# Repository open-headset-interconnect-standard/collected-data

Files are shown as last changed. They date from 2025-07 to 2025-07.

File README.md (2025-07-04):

# collected-data
Measurement data that has been collected first-hand, that would benefit the community.

That is to say: don't post information you got from somewhere else here.

## What to include
To create a pull-request into this repo (read: to publish data here):

* Create your own directory for the data, unless you are contributing to an existing collection of measurements.
* Create a `README.md` in that directory that explains what the data is and why it's useful to the community (if not obvious).
* Include the measurement meathodology:
  * What measurement equipment was used?  Make and model, where appropriate.  Was is calibrated?
  * Configuration of measurement equipment, device under test, and anything else relevant.  What was connected to what?
  * Any other relevant information that would help a reader understand just what they're looking at.
* Include the data in both raw format, and analyzed format, where appropriate.  For example:
  * Include an image that shows the conclusion quickly: "The SWR at 145MHz is 1.2:1"
  * Include the .s2p file that was used to generate that conclusion, so that others can analyze the data differently: "Sure, but it's entirely reactive. The X=0 point is at 162MHz."  Or whatever.

@SmittyHalibut 2025-07-02

# Data!

[Audio Isolation Transformer measurements](Audio%20Transformers/)

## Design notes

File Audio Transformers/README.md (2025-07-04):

# 1. Audio Transformer measurements

- [1. Audio Transformer measurements](#1-audio-transformer-measurements)
    - [1.1. Measurement setup](#11-measurement-setup)
- [2. Measurement Results](#2-measurement-results)
    - [2.1. Through Calibration](#21-through-calibration)
    - [2.2. Bourns SM-LP-5001](#22-bourns-sm-lp-5001)
    - [2.3. PXSW PX-MB-CPC E-9818](#23-pxsw-px-mb-cpc-e-9818)
    - [2.4. ED8 Permalloy](#24-ed8-permalloy)
    - [2.5. EI-14 eBay](#25-ei-14-ebay)
    - [2.6. EI-14 TL016 "Mouser" (Xicon?)](#26-ei-14-tl016-mouser-xicon)
- [3. All transformers, compared by voltage](#3-all-transformers-compared-by-voltage)
    - [3.1. 100mV](#31-100mv)
    - [3.2. 3V](#32-3v)
- [4. Test Board Details](#4-test-board-details)

I got reports that audio frequency response was ... pretty terrible ... on a product I made.  So I wanted to measure the actual frequency response of several 1:1 audio transformers to see if there were better options.

I made a [circuit board](#3-test-board-details) that would take several common transformer footprints and present their inputs and outputs with BNC sockets (for easy connection to my test gear), bought several transformers, wired it all up, and got to measuring!

In the immortal words of Mark Watney:
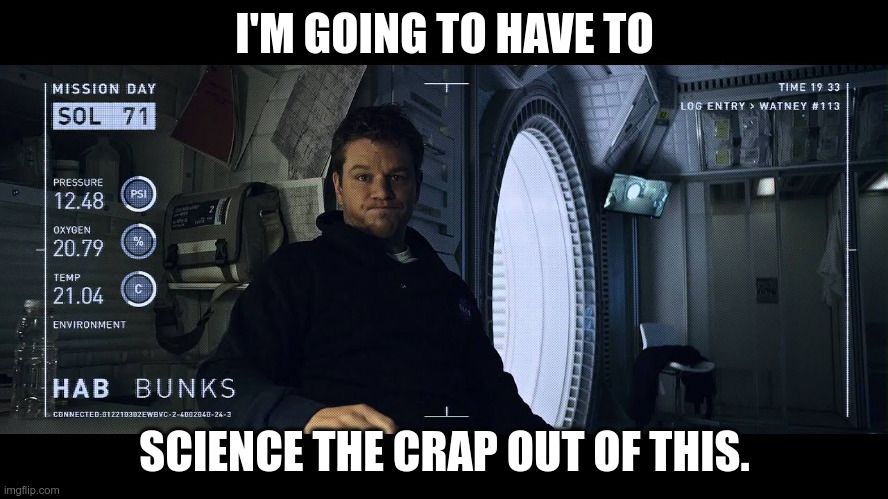
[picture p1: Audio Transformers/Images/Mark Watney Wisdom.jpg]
I'm going to have to Science the CRAP out of this.


> @SmittyHalibut 2025-07-02

## 1.1. Measurement setup

I designed a [test board](#3-test-board-details) and soldered several different audio transformers to each one.  The board has BNC sockets for easy connection to my other gear.

I used an [Analog Discovery 2](https://digilent.com/shop/analog-discovery-2-100ms-s-usb-oscilloscope-logic-analyzer-and-variable-power-supply/) to take all measurements.  It had a [BNC Adapter](https://digilent.com/shop/bnc-adapter-for-analog-discovery/) attached.  The signal generator was set to 50&Omega;, and the scope was set to DC coupled.

I used [Waveforms](https://digilent.com/shop/out-of-the-box-solutions/) to perform the measurements.  The Workspace configuration file is [included here](./Data/Audio%20Network%20Analyzer.dwf3work).

In short, it uses the Network tool to measure Amplitude, Phase, THD and THD+N.  A script automates taking the same measurements at several signal voltage levels ranging from 100mV to 5V.  The load on the secondary side of the transformers in a 1k&Omega; resistor, so you can calculate the power being transferred.

The cables were 1m long RG316 with BNC males on either end, purchased from [Packtenna](https://www.packtenna.com/store/p14/3%27_RG-316_Coax_with_2_Right_Angle_BNC_connectors.html#/).  Wavegen1 and Scope2 were connected together with a BNC T (remember those? THIS IS WHY WE HOARD) to the Primary of the transformer.  Scope1 was connected to the Secondary of the transformer.

The test boards (below) allow you to put a component in series and parallel with each input and output.  For these measurements, I used a 0&Omega; jumper in series, and a 1k&Omega; resistor in parallel with the Secondary.  So the signal generator was seeing a 1k&Omega; load, transformed by whatever ratio the transformer was using.  (It's SUPPOSED to be 1:1, but nothing is perfect.)

# 2. Measurement Results

GIVE ME THE DATA!

The graphs below show the 1v measurements, since that's a pretty typical signal level.  However, the curves change pretty dramatically with voltage/power.

## 2.1. Through Calibration

Just to show the correctness and limitations of my measurement setup (THD and THD+N measurements are pretty limited), I measured a BNC barrel connector, no transformer, no boards, no 1k&Omega; load.  This should be as close to flat as possible.

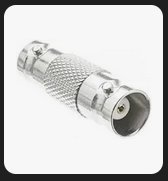
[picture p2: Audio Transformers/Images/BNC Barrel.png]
BNC Barrel


* [Raw measurement data.](Data/Through%20Calibration/README.md)

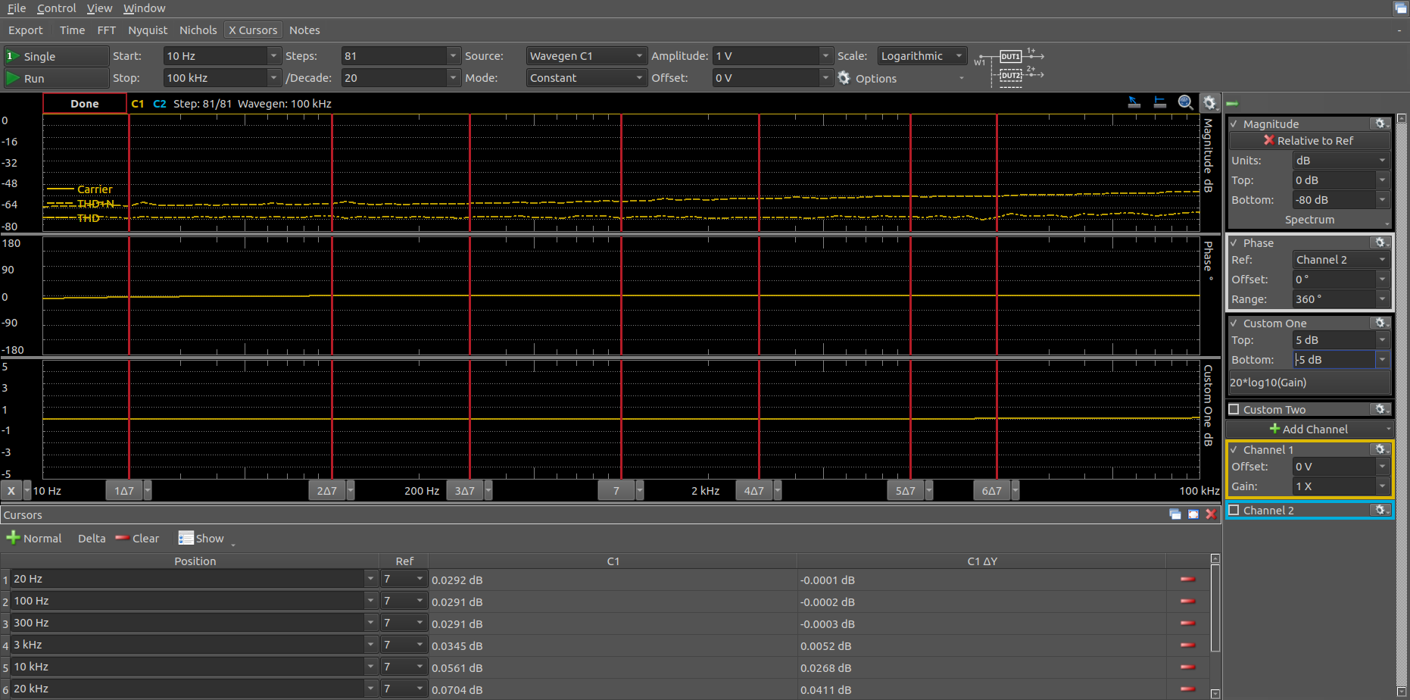
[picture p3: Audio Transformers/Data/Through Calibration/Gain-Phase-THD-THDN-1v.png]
Through Calibration


## 2.2. Bourns SM-LP-5001

This is the transformer I was using that my customer complained about.  It's readily available from trusted distributors like Mouser or DigiKey.

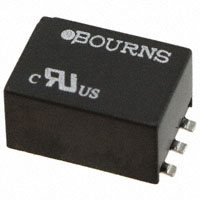
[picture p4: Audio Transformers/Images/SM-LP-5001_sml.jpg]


Links:

* [Manufacturer product page.](https://bourns.com/products/magnetic-products/details/transformers-signal/sm-lp-5001)
* [Mouser product page.](https://www.mouser.com/ProductDetail/Bourns/SM-LP-5001?qs=y2ToytHrPzhgLhPbZb8L1Q%3D%3D)
* [Raw measurement data.](Data/Bourns%20SM-LP-5001/README.md)

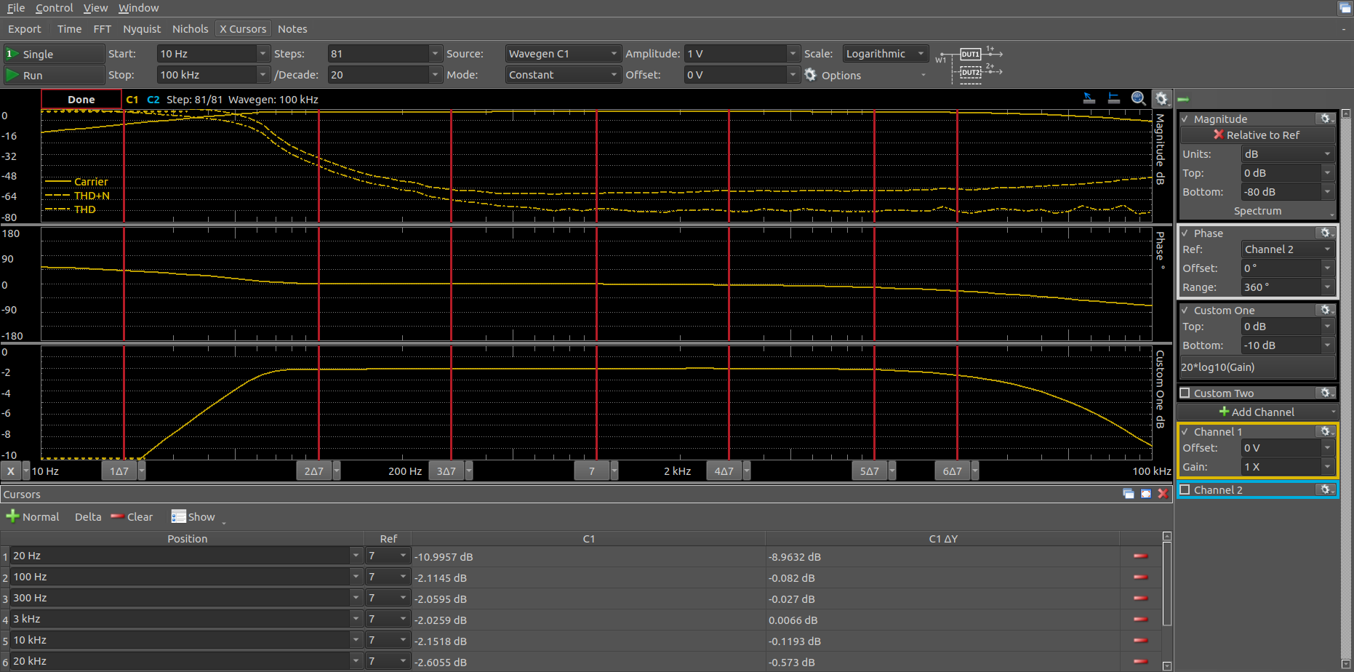
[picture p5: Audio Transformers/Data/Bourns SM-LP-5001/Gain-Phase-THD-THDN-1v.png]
Bourns SM-LP-5001


## 2.3. PXSW PX-MB-CPC E-9818

I don't know what to call this one.  I got it [from AliExpress](https://www.aliexpress.us/item/3256807819143335.html) for about $15 US (including shipping.)  The brand looks like PXSW, but there are other apparently similar products from [TITAk (called HT-MB-CPC)](https://www.aliexpress.us/item/3256809080493006.html) and [ZXY Audio (called ZXY-2207)](https://www.aliexpress.us/item/3256808740799076.html).

I don't endorse any of these more than the other, they're pretty typical faceless vendors on AliExpress.  The one I measured is the first link above; I can't speak to the others, but they seem very similar.

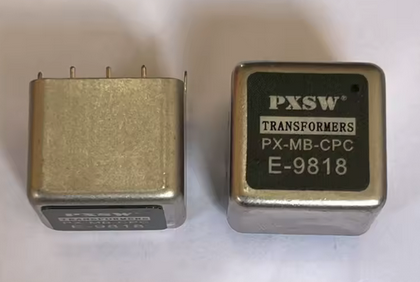
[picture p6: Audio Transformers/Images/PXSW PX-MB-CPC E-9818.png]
PXSW PX-MB-CPC E-9818


Links:

* [AliExpress page I bought from](https://www.aliexpress.us/item/3256807819143335.html)
* I can't find any manufacturer information on any of these.  If you can find a first-source, please submit an issue.
* [Raw measurement data.](Data/PXSW%20PX-MB-CPE%20E-9818/README.md)

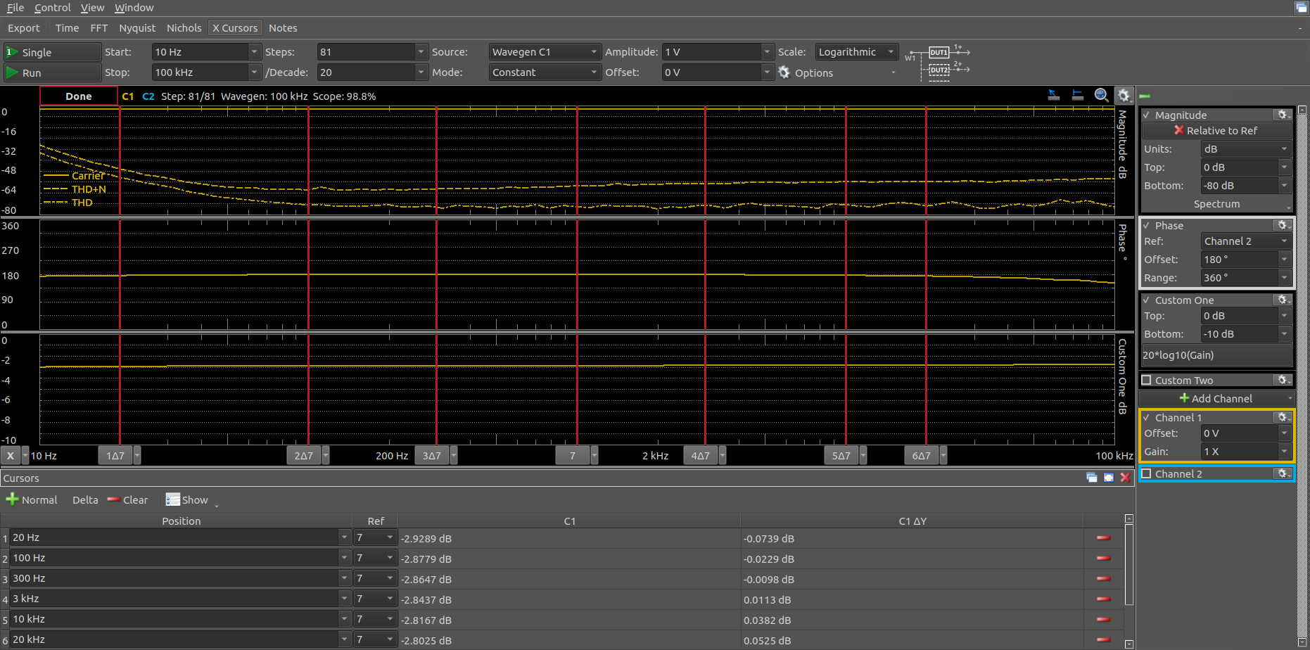
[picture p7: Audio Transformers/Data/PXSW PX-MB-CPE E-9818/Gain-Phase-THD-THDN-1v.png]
PXSW PX-MB-CPC E-9818


## 2.4. ED8 Permalloy

This is another one I don't quite know what to call it.  The Aliexpress listing just refers to it as "SMD ED8 Permalloy Audio Transformer."  It does claim a frequency range of 200Hz-20kHz.

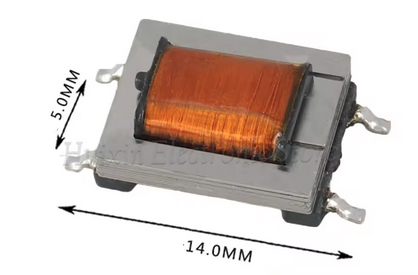
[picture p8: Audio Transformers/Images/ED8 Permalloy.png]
ED8 Permalloy


Links:
* [AliExpress page I bought from](https://www.aliexpress.us/item/3256804057242738.html)
* I can't find any manufacturer information on any of these.  If you can find a first-source, please submit an issue.
* [Raw measurement data.](Data/ED8%20Aliexpress/README.md)

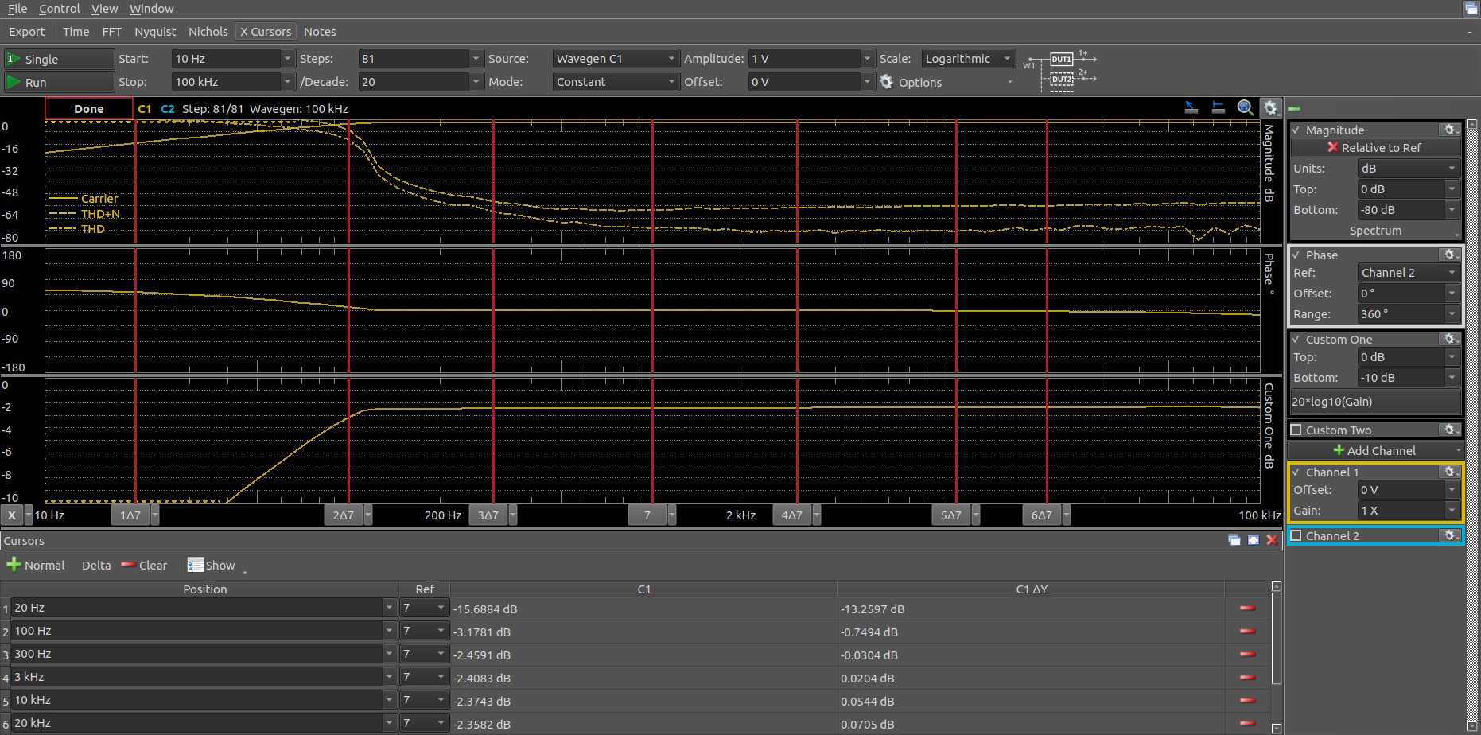
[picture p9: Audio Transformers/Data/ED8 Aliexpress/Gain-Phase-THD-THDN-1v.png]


## 2.5. EI-14 eBay

The listing I bought from is no longer available, but I provide a link to a similar part below.  These are very inexpensive, and through-hole which makes them good candidates for hack-together solutions.

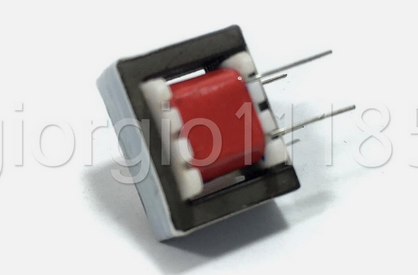
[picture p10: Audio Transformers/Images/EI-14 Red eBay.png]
EI-14 eBay


Links:
* [eBay listing similar to what I bought](https://www.ebay.com/itm/405470535902)
* [Raw measurement data.](Data/EI-14%20Red%20eBay/README.md)

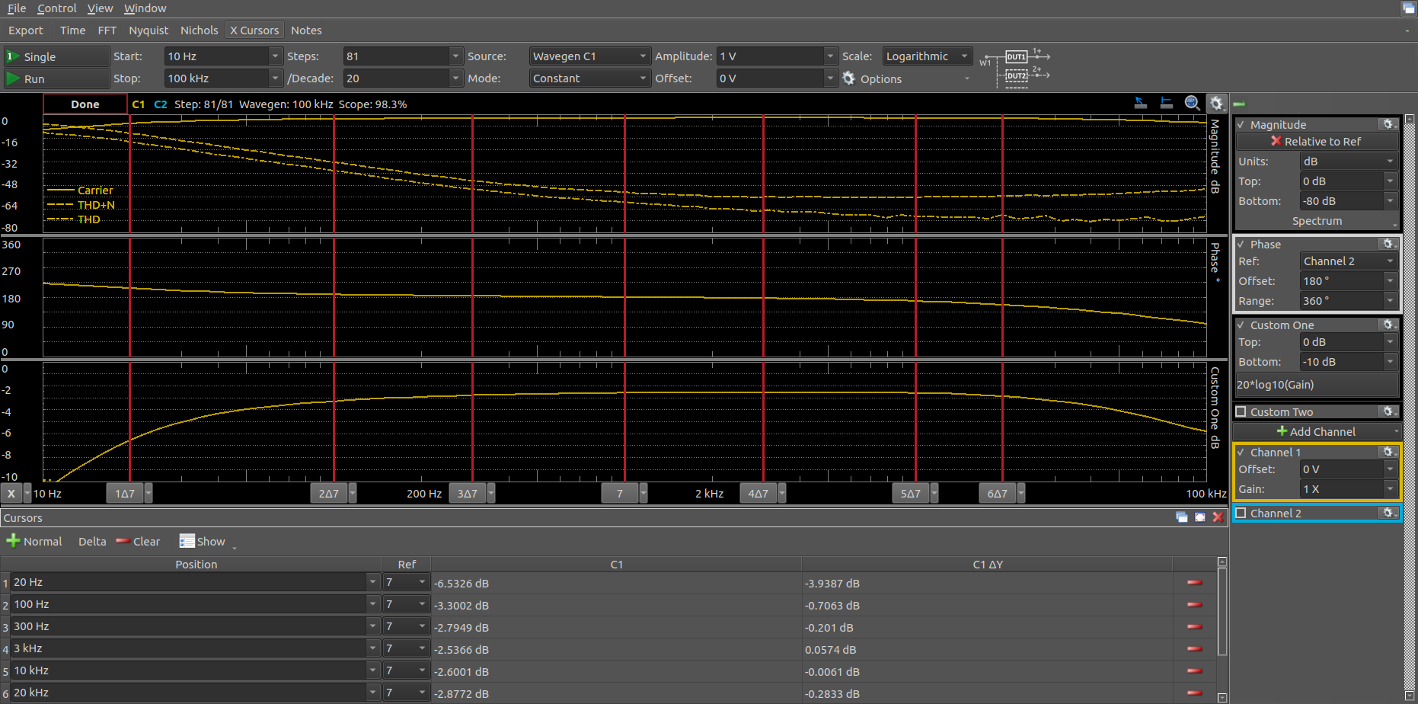
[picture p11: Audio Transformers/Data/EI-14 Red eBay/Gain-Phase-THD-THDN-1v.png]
EI-14 eBay


## 2.6. EI-14 TL016 "Mouser" (Xicon?)

I don't remember buying these. :-D  They are stamped `Mouser` on the top, and labeled `TL016` on the side.  Searching Mouser for `TL016` finds the Xicon part below, which seems to match the description of what I have.  So, let's go with that.

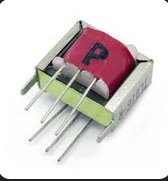
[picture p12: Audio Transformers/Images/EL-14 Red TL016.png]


Links:
* [Mouser product page.](https://www.mouser.com/ProductDetail/Xicon/42TL016-RC?qs=AoVmiMTrbDJMqsZex%252BybNw%3D%3D)
* [Raw measurement data.](Data/EI-14%20Red%20TL016%20Mouser/README.md)

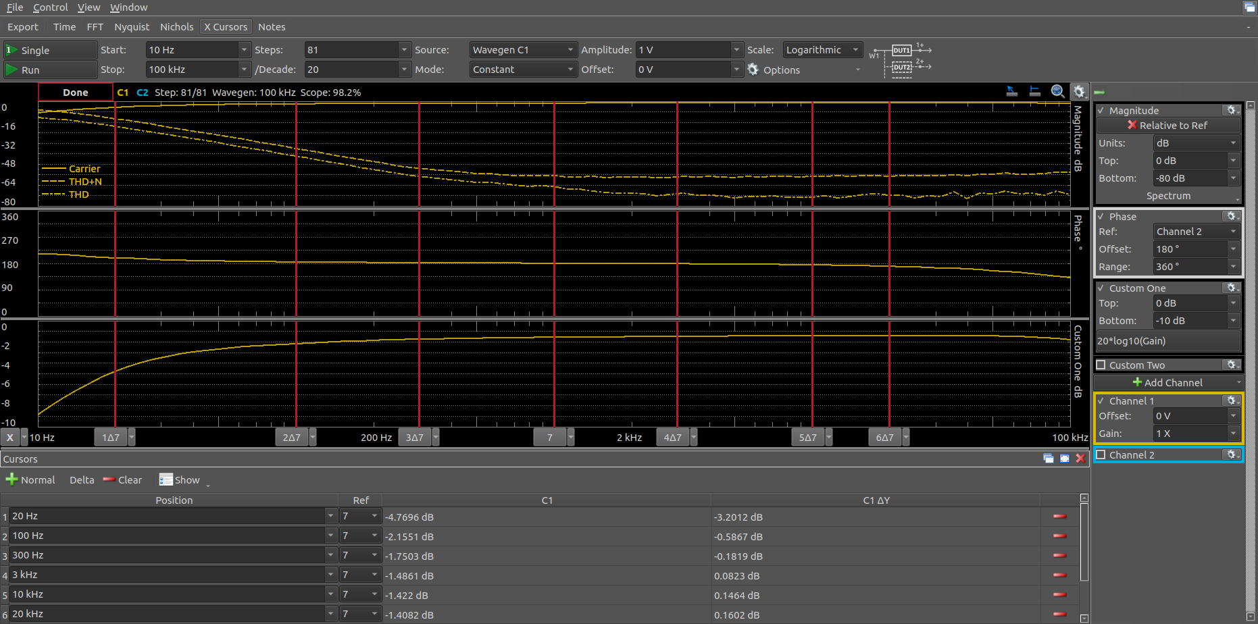
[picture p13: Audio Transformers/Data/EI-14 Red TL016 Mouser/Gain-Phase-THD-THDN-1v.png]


# 3. All transformers, compared by voltage

## 3.1. 100mV

For weaker signals, microphones, etc.  Note how most graphs are flatter, but possibly noisier.

Bourns SM-LP-5001:
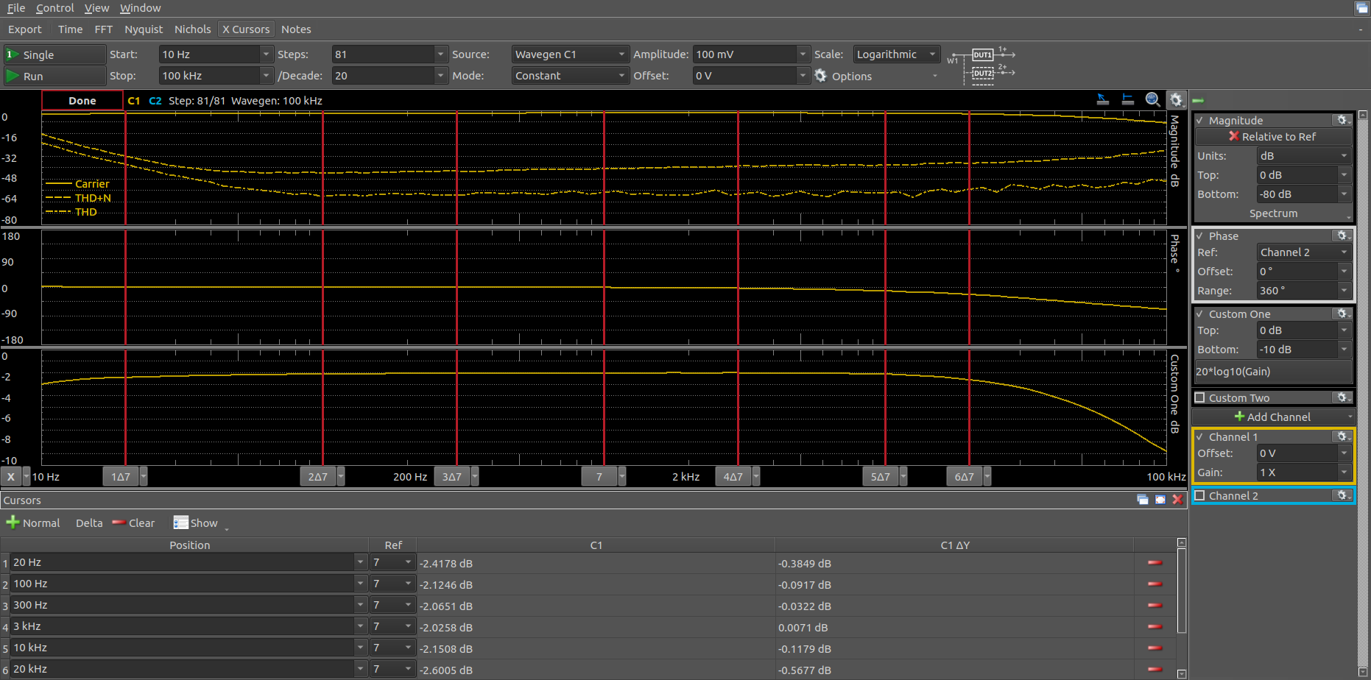
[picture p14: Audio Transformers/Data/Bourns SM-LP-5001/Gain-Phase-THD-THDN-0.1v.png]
Bourns SM-LP-5001


PXSW PX-MB-CPC E-9818:
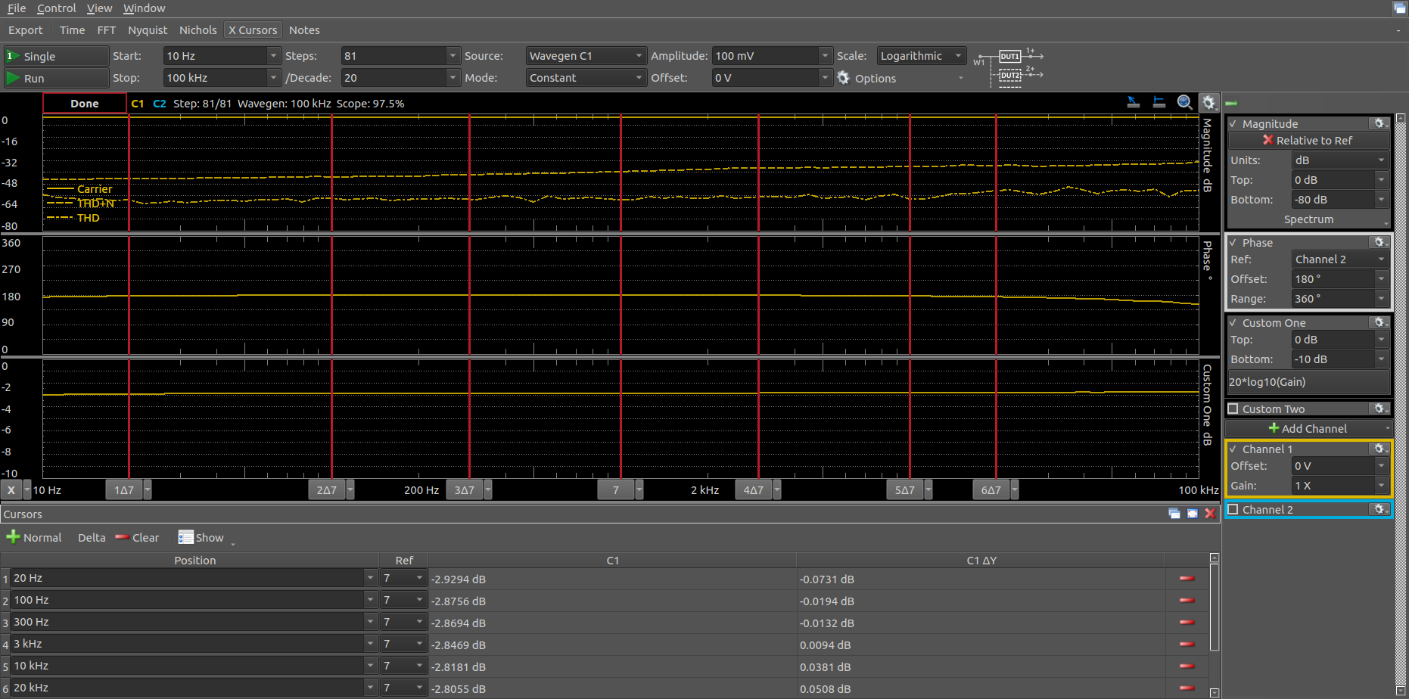
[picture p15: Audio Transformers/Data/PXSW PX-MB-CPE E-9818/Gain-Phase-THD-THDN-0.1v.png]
PXSW PX-MB-CPC E-9818


ED8 Permalloy:
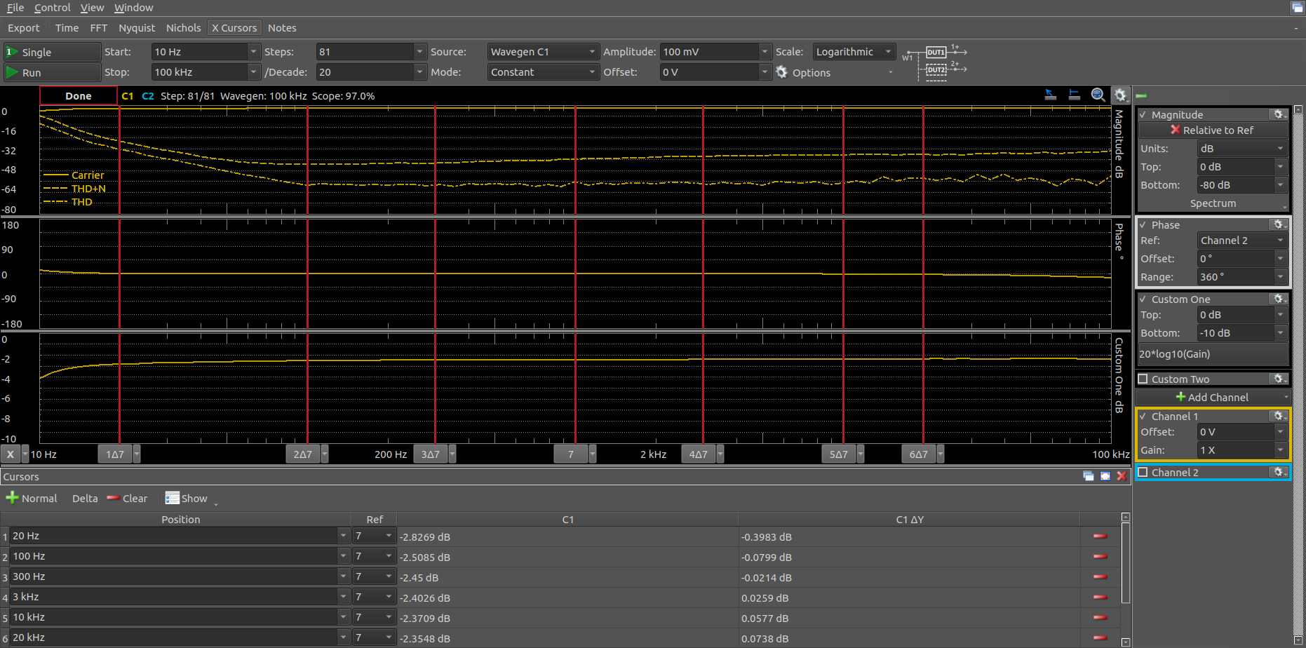
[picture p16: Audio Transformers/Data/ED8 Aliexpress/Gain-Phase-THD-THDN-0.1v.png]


EI-14 eBay:
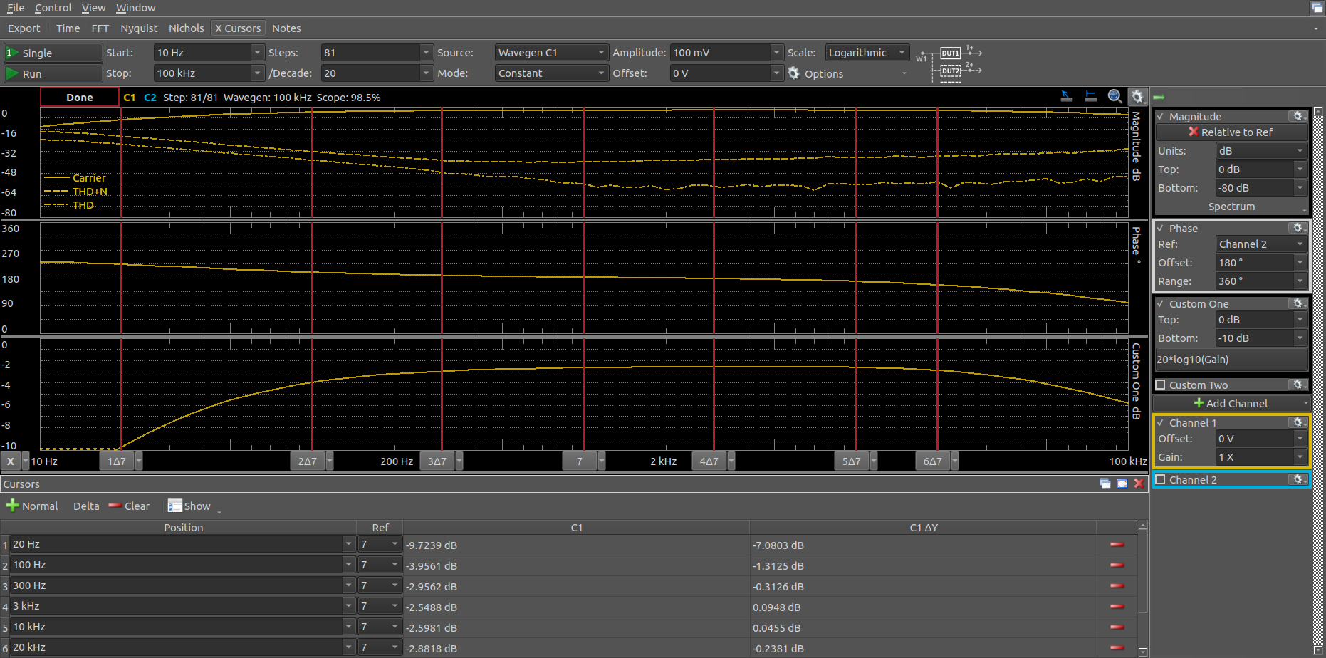
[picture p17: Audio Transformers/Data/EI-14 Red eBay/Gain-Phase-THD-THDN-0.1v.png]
EI-14 eBay


EI-14 TL016:
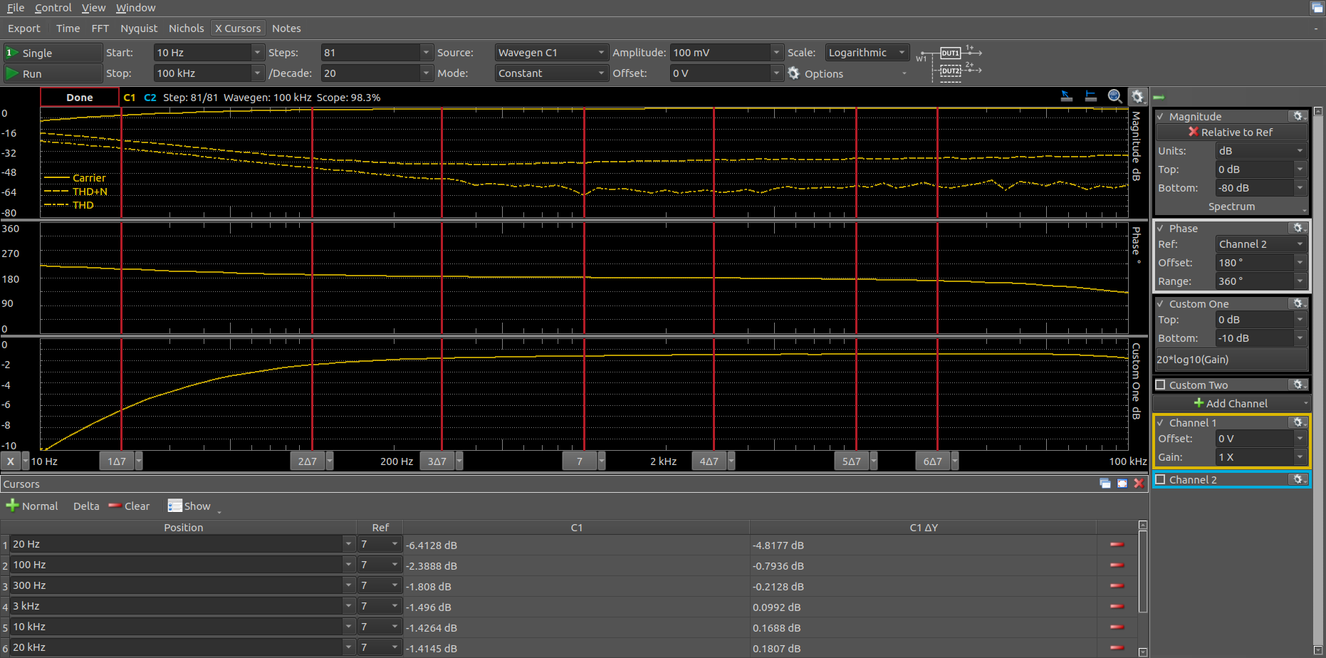
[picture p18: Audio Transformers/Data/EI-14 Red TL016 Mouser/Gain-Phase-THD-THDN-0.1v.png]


## 3.2. 3V

For stronger signals, speaker outputs, etc.

Bourns SM-LP-5001:
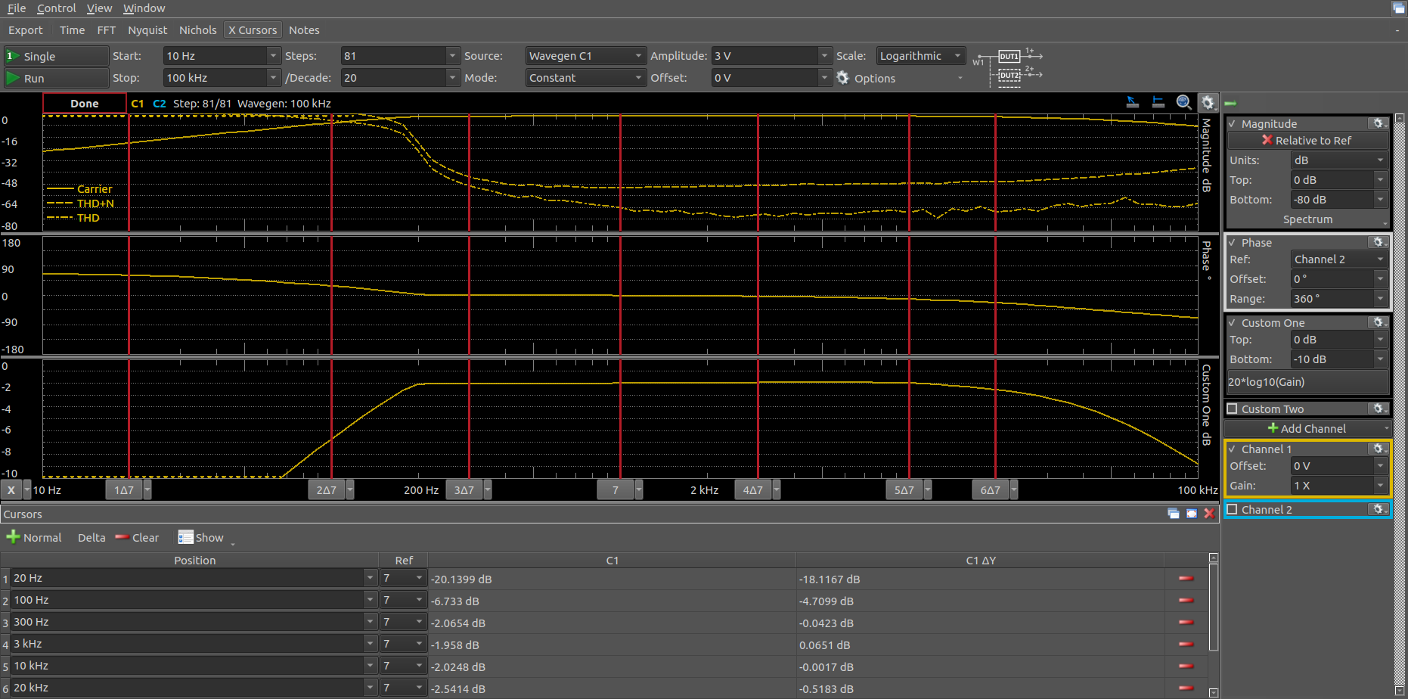
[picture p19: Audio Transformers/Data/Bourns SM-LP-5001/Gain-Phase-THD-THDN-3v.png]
Bourns SM-LP-5001


PXSW PX-MB-CPC E-9818:
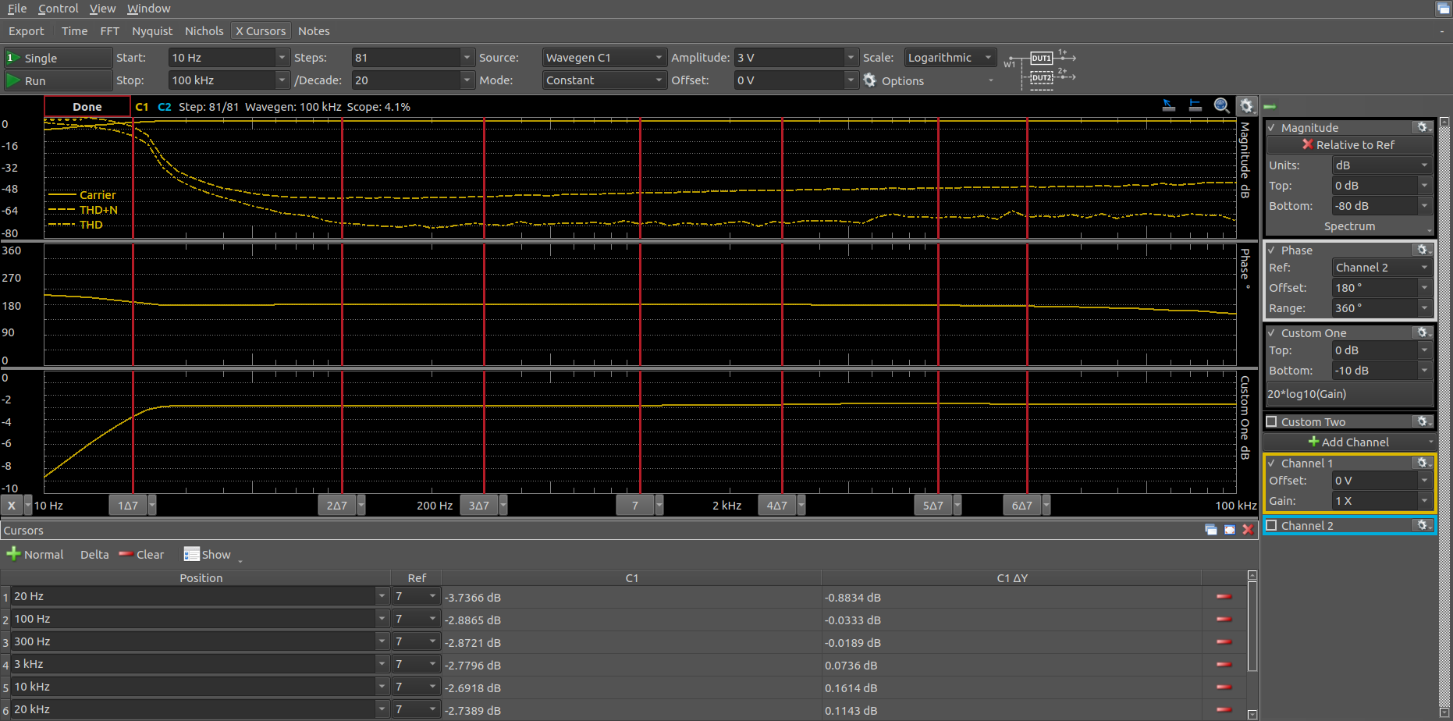
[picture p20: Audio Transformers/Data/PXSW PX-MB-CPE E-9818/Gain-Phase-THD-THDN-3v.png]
PXSW PX-MB-CPC E-9818


ED8 Permalloy:
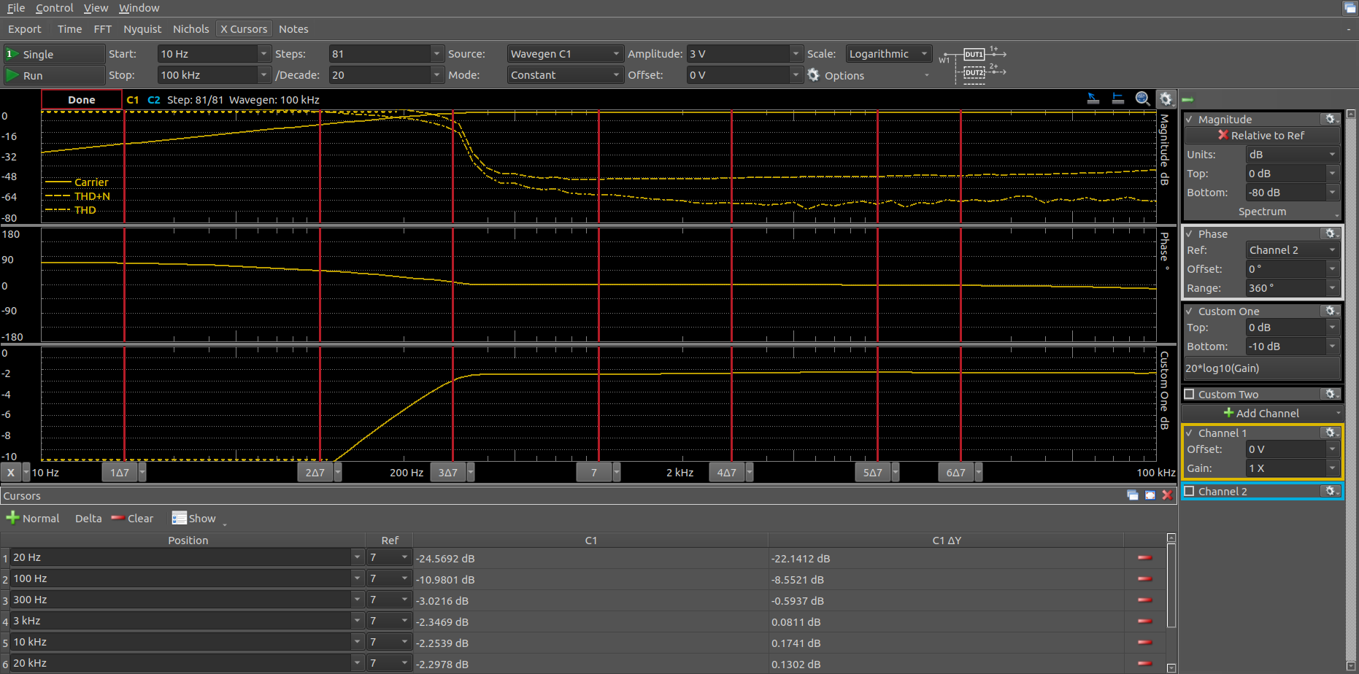
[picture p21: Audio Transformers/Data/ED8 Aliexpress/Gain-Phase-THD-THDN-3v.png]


EI-14 eBay:
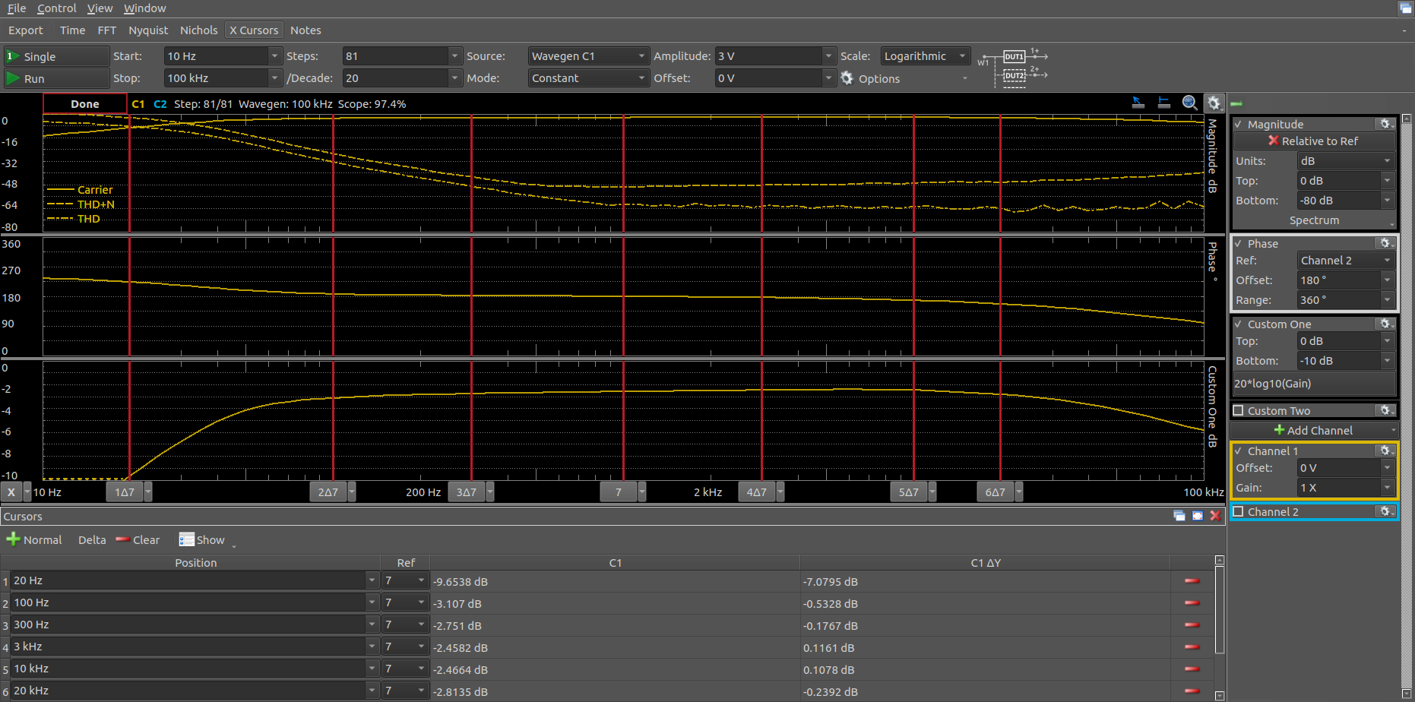
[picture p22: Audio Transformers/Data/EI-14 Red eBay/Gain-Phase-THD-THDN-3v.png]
EI-14 eBay


EI-14 TL016:
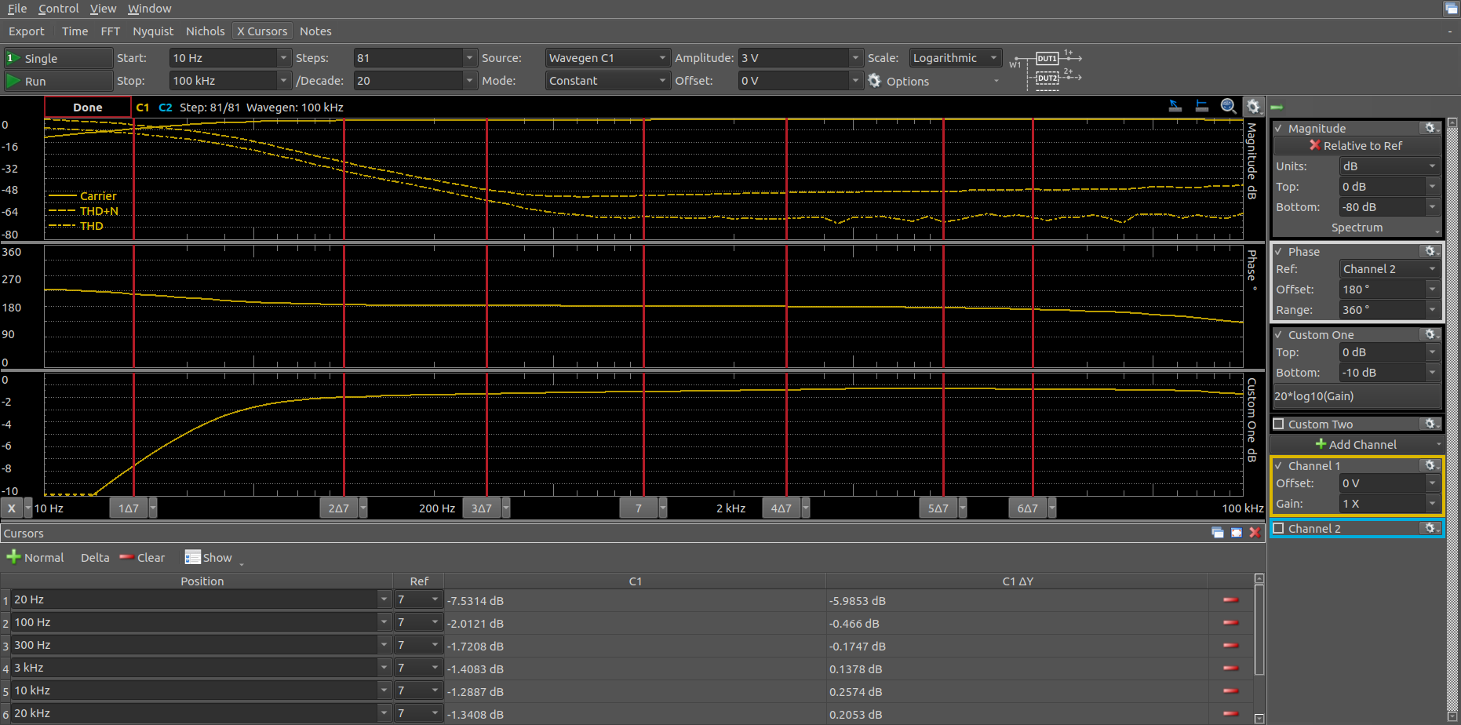
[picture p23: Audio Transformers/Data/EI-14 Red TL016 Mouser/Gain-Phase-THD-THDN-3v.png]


# 4. Test Board Details

KiCAD files are [here](Transformer-FRA/).  Below are snapshot images taken on 2025-07-02.

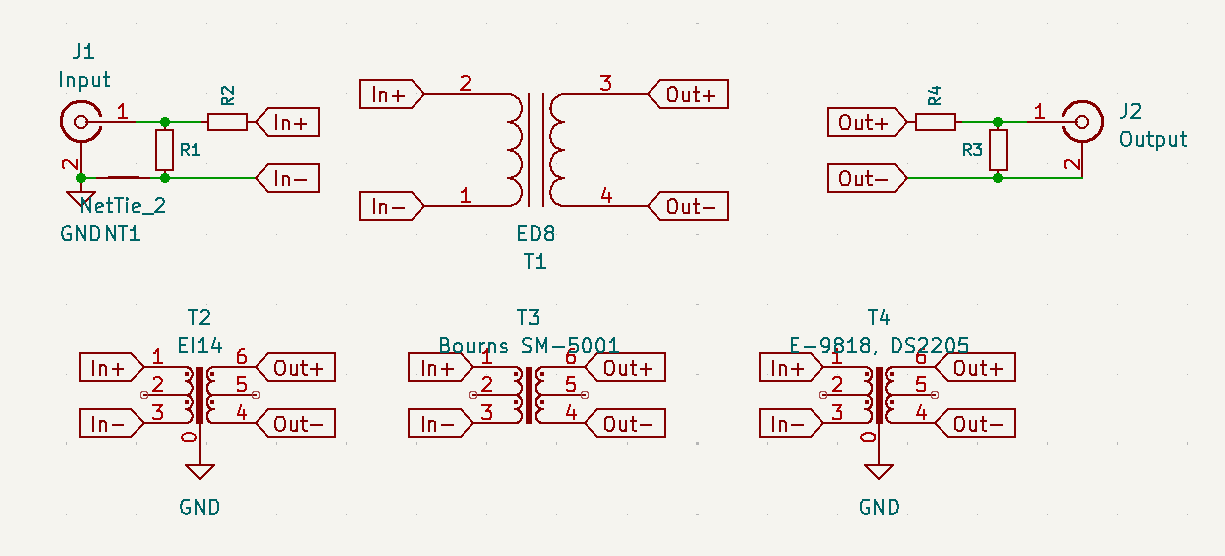
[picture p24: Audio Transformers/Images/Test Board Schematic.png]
Schematic


Board

I hand assembled 0R resistors in series (R2 and R4), and a 1k load resistor on the port connected to the scope input on the AD2 (R3).  The input load resistor (R1) was left unpopulated.  So the transformers were seeing a 1k load, transformed by the transformer.

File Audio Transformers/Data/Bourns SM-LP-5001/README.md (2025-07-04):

# Data for the Bourns SM-LP-5001

## CSV raw data

* [100mV](./Gain-Phase-THD-THDN-0.1v.csv)
* [300mV](./Gain-Phase-THD-THDN-0.3v.csv)
* [1V](./Gain-Phase-THD-THDN-1v.csv)
* [2V](./Gain-Phase-THD-THDN-2v.csv)
* [3V](./Gain-Phase-THD-THDN-3v.csv)
* [5V](./Gain-Phase-THD-THDN-5v.csv)

## Graphs

100mV:
100mV

300mV:
300mV

1V:
1V

2V:
2V

3V:
3V

5V:
5V

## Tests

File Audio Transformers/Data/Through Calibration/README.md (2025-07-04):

# Data for a Through Calibration.

No Transformer at all. This is used to validate the measurement equipment.

## CSV raw data

* [100mV](./Gain-Phase-THD-THDN-0.1v.csv)
* [300mV](./Gain-Phase-THD-THDN-0.3v.csv)
* [1V](./Gain-Phase-THD-THDN-1v.csv)
* [2V](./Gain-Phase-THD-THDN-2v.csv)
* [3V](./Gain-Phase-THD-THDN-3v.csv)
* [5V](./Gain-Phase-THD-THDN-5v.csv)

## Graphs

100mV:
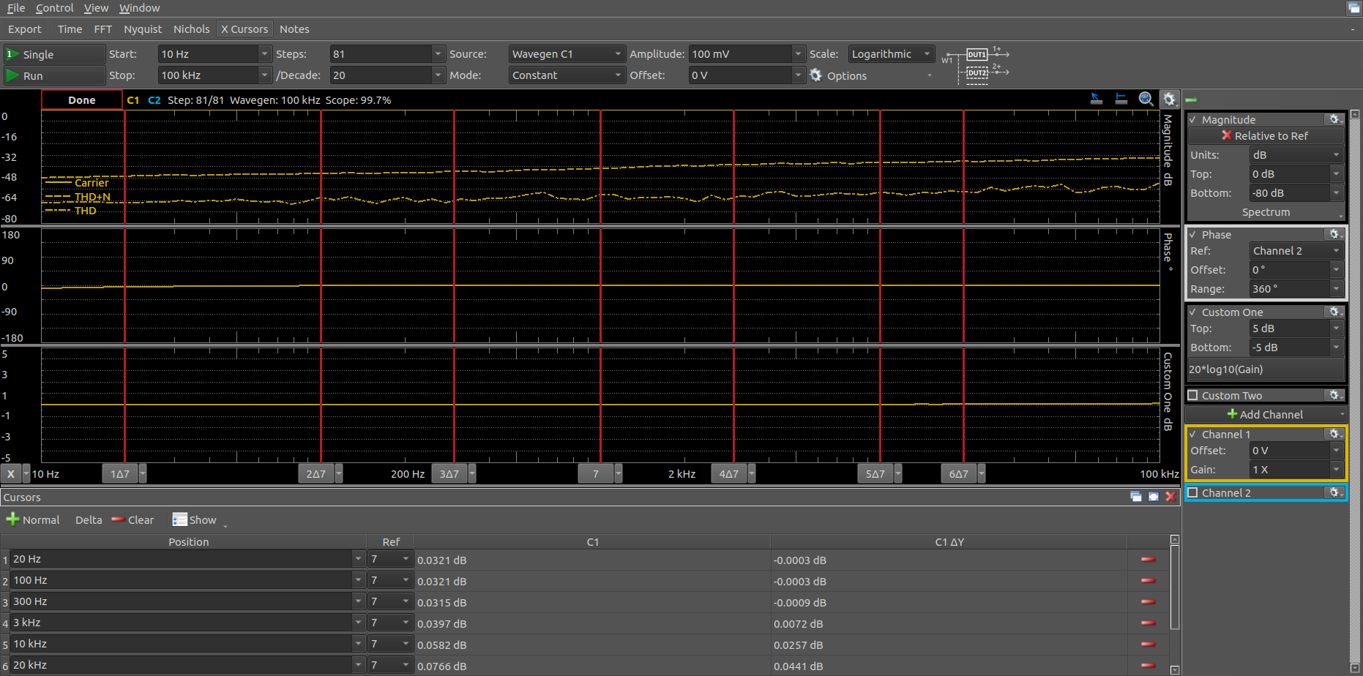
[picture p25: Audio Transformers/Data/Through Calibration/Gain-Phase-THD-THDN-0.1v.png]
100mV


300mV:
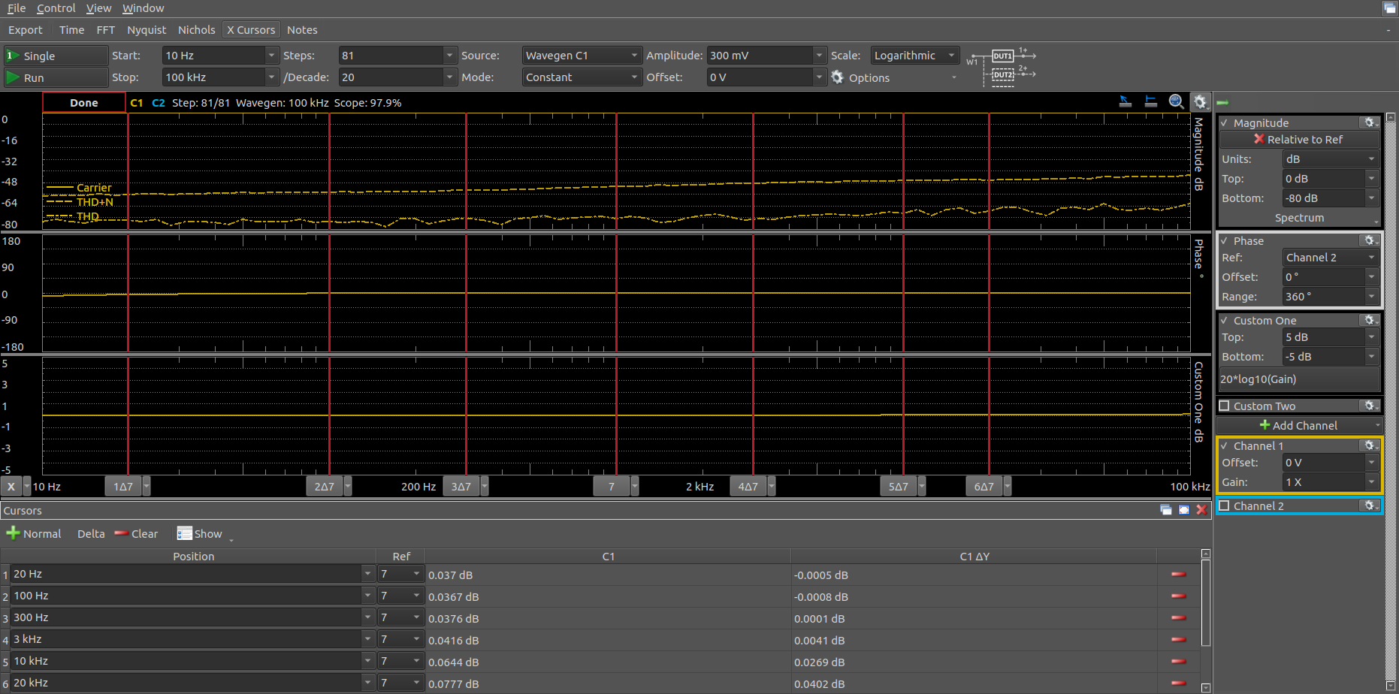
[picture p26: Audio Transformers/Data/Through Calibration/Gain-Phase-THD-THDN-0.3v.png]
300mV


1V:
1V

2V:
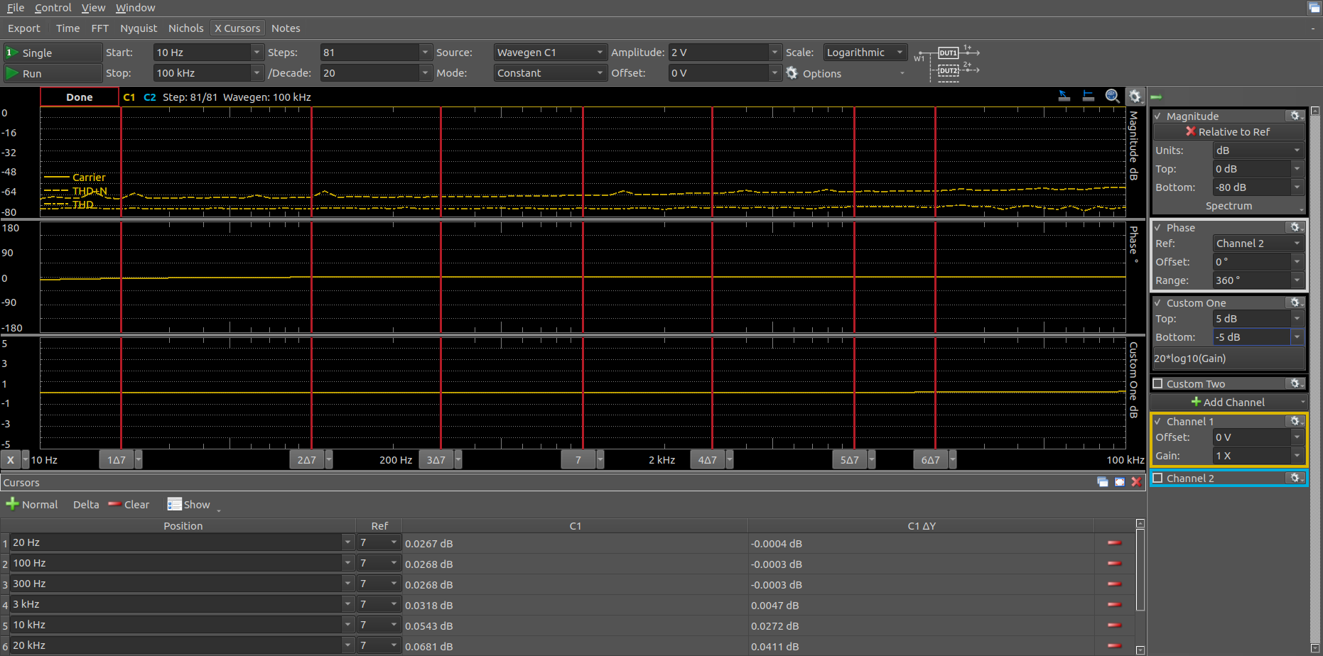
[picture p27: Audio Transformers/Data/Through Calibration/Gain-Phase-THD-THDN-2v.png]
2V


3V:
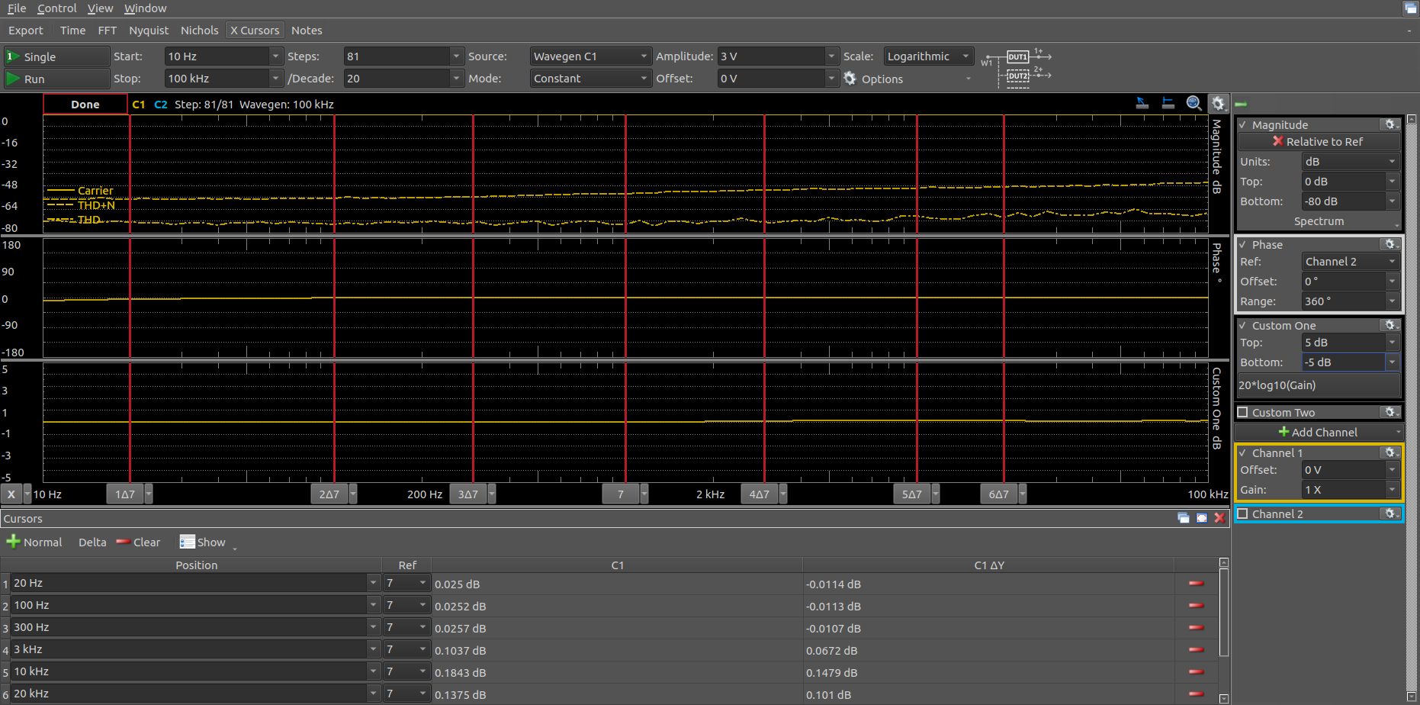
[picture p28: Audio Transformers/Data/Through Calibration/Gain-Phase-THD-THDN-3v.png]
3V


5V:
5V

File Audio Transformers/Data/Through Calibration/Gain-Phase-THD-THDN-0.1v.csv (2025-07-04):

#Digilent WaveForms Network Analyzer - Bode
#Device Name: Discovery2
#Serial Number: SN:210321A7F3E5
#Date Time: 2025-07-04 15:05:11.990
#Start: 10 Hz
#Stop: 100000 Hz
#Steps: 81
#Wavegen: Wavegen C1
#Amplification: 1 X
#Settle: 10 ms
#MinPeriods: 32
#Channel: Channel 1
#Range: 5.55283 V
#Offset: 0.000243159 V
#Relative: no
Frequency (Hz) | Channel 1 Magnitude (dB) | Channel 1 Magnitude THD+N (dB) | Channel 1 Magnitude THD (dB) | Channel 1 Phase (deg) | Channel 1 Custom One (dB)
10 | 0.03135181430366201 | -47.7925486187669 | -65.48813821918739 | -9.783904763893396 | 0.03135181430366201
11.22018454301963 | 0.03099580894709313 | -47.2602155958361 | -65.54954914166152 | -8.72703162474302 | 0.03099580894709313
12.589254117941675 | 0.031238479557986375 | -47.4224963640523 | -64.86822111018036 | -7.799133542867992 | 0.031238479557986375
14.12537544622754 | 0.03230195686225268 | -47.26244358265228 | -65.03406190187688 | -6.961223604143621 | 0.03230195686225268
15.848931924611142 | 0.03142930147068772 | -46.714910240317295 | -64.78328109587625 | -6.218746505992669 | 0.03142930147068772
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

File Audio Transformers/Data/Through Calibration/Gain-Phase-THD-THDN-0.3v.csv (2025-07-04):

#Digilent WaveForms Network Analyzer - Bode
#Device Name: Discovery2
#Serial Number: SN:210321A7F3E5
#Date Time: 2025-07-04 15:05:44.012
#Start: 10 Hz
#Stop: 100000 Hz
#Steps: 81
#Wavegen: Wavegen C1
#Amplification: 1 X
#Settle: 10 ms
#MinPeriods: 32
#Channel: Channel 1
#Range: 5.55283 V
#Offset: 0.000243159 V
#Relative: no
Frequency (Hz) | Channel 1 Magnitude (dB) | Channel 1 Magnitude THD+N (dB) | Channel 1 Magnitude THD (dB) | Channel 1 Phase (deg) | Channel 1 Custom One (dB)
10 | 0.037512983265305395 | -57.21673396519655 | -74.78457858902581 | -9.765628865391953 | 0.037512983265305395
11.22018454301963 | 0.037525367426166564 | -56.786420022447395 | -73.23174322019567 | -8.724335911649689 | 0.037525367426166564
12.589254117941675 | 0.03688067229138768 | -56.76001126891798 | -74.50338406879054 | -7.793349359390618 | 0.03688067229138768
14.12537544622754 | 0.037220351878634865 | -56.656392706838204 | -75.6899010964951 | -6.963077762343758 | 0.037220351878634865
15.848931924611142 | 0.03751045805399789 | -55.6876469211889 | -73.57624785282844 | -6.213789498282637 | 0.03751045805399789
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

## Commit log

2025-07-04 Audio Transformer measurements.
    [Gain-Phase-THD-THDN-0.1v.csv, Gain-Phase-THD-THDN-0.3v.csv, Gain-Phase-THD-THDN-1v.csv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]
2025-07-04 Added images of the transformers. Fixed Schematic and PCB images.
